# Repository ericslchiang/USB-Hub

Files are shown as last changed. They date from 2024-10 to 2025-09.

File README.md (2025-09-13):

## CHIP-8 Emulator by ericslchiang
### March 18th 2025  

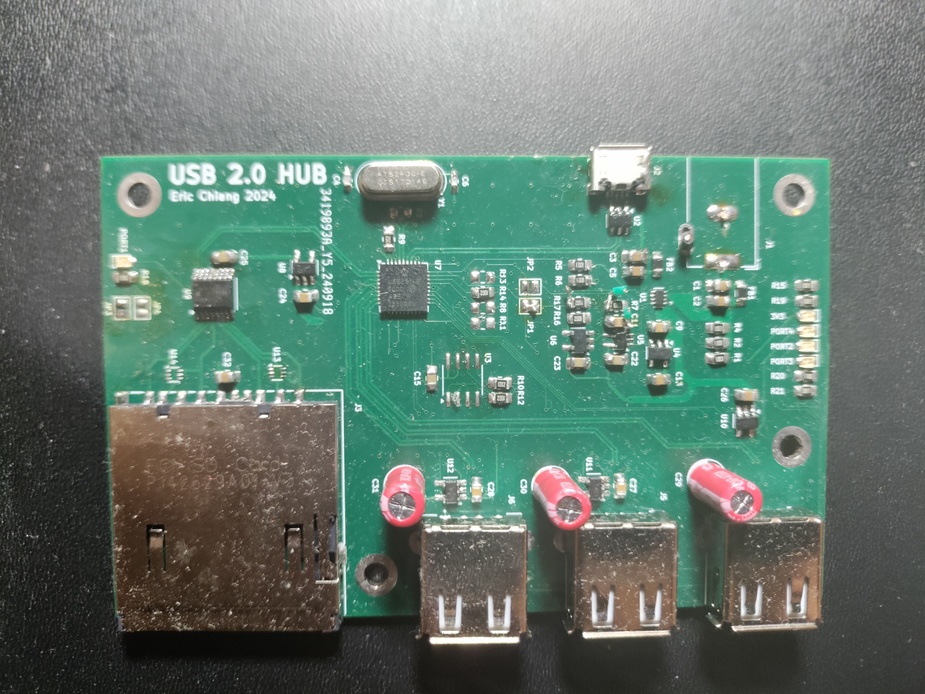
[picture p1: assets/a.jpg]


######
An USB 2.0 Hub with three downstream USB 2.0 Ports and one SD card slot. Built using a Microchip USB2514B for USB Hub control and a Genesys Logic GL823K USB 2.0 to SD card converter IC.  
Routed on a 4-layer PCB with controlled impedances and length controlled USB differential routes. All design files in KiCAD.

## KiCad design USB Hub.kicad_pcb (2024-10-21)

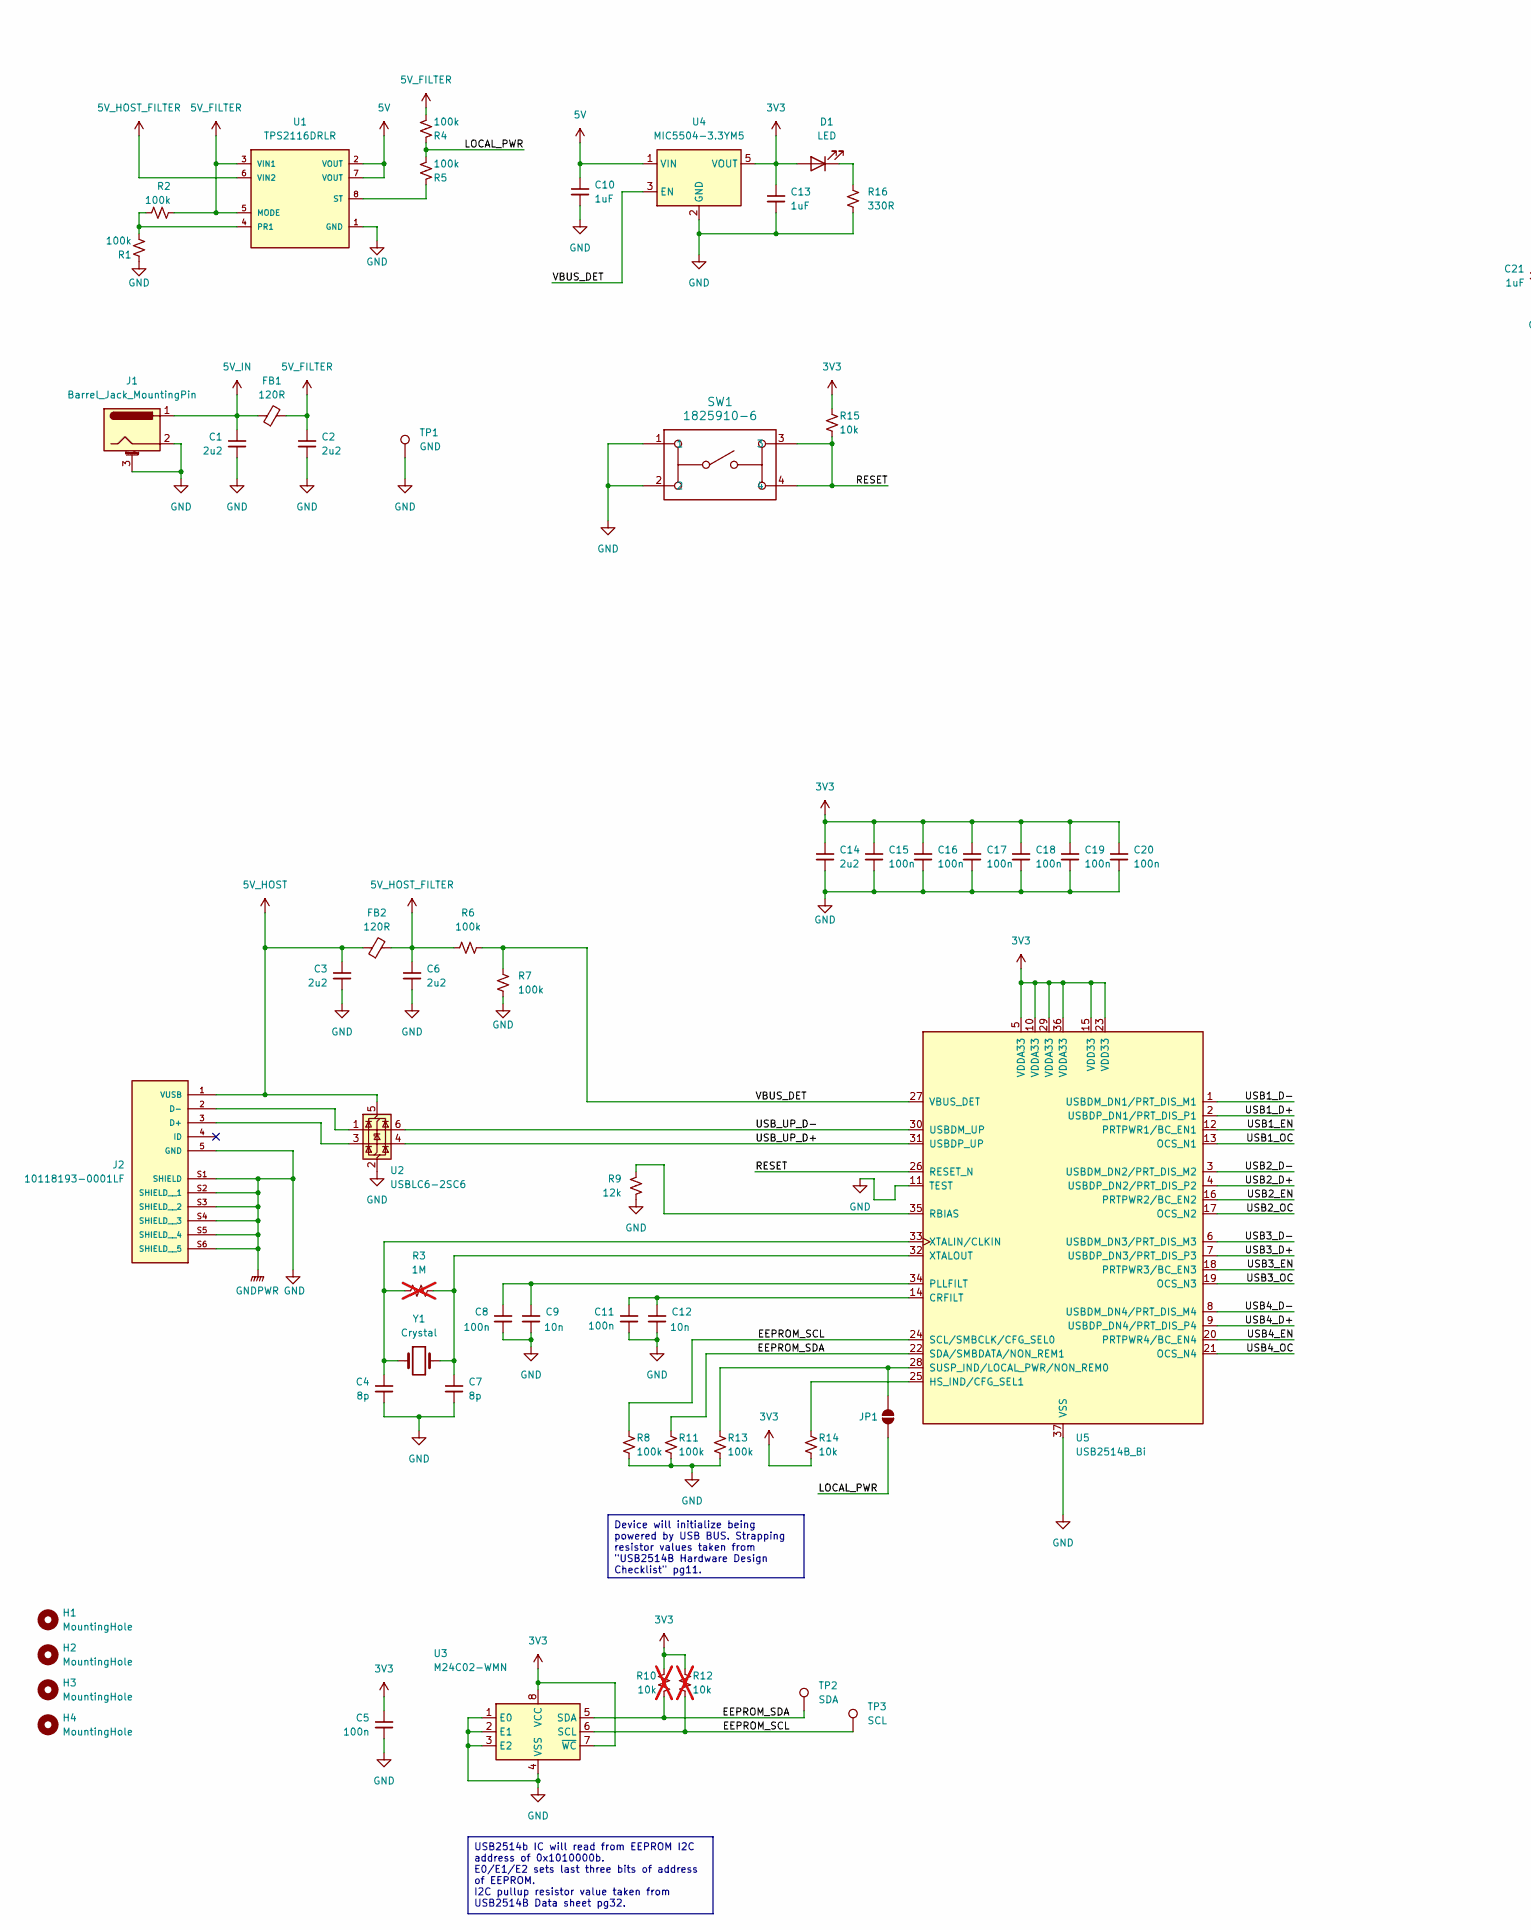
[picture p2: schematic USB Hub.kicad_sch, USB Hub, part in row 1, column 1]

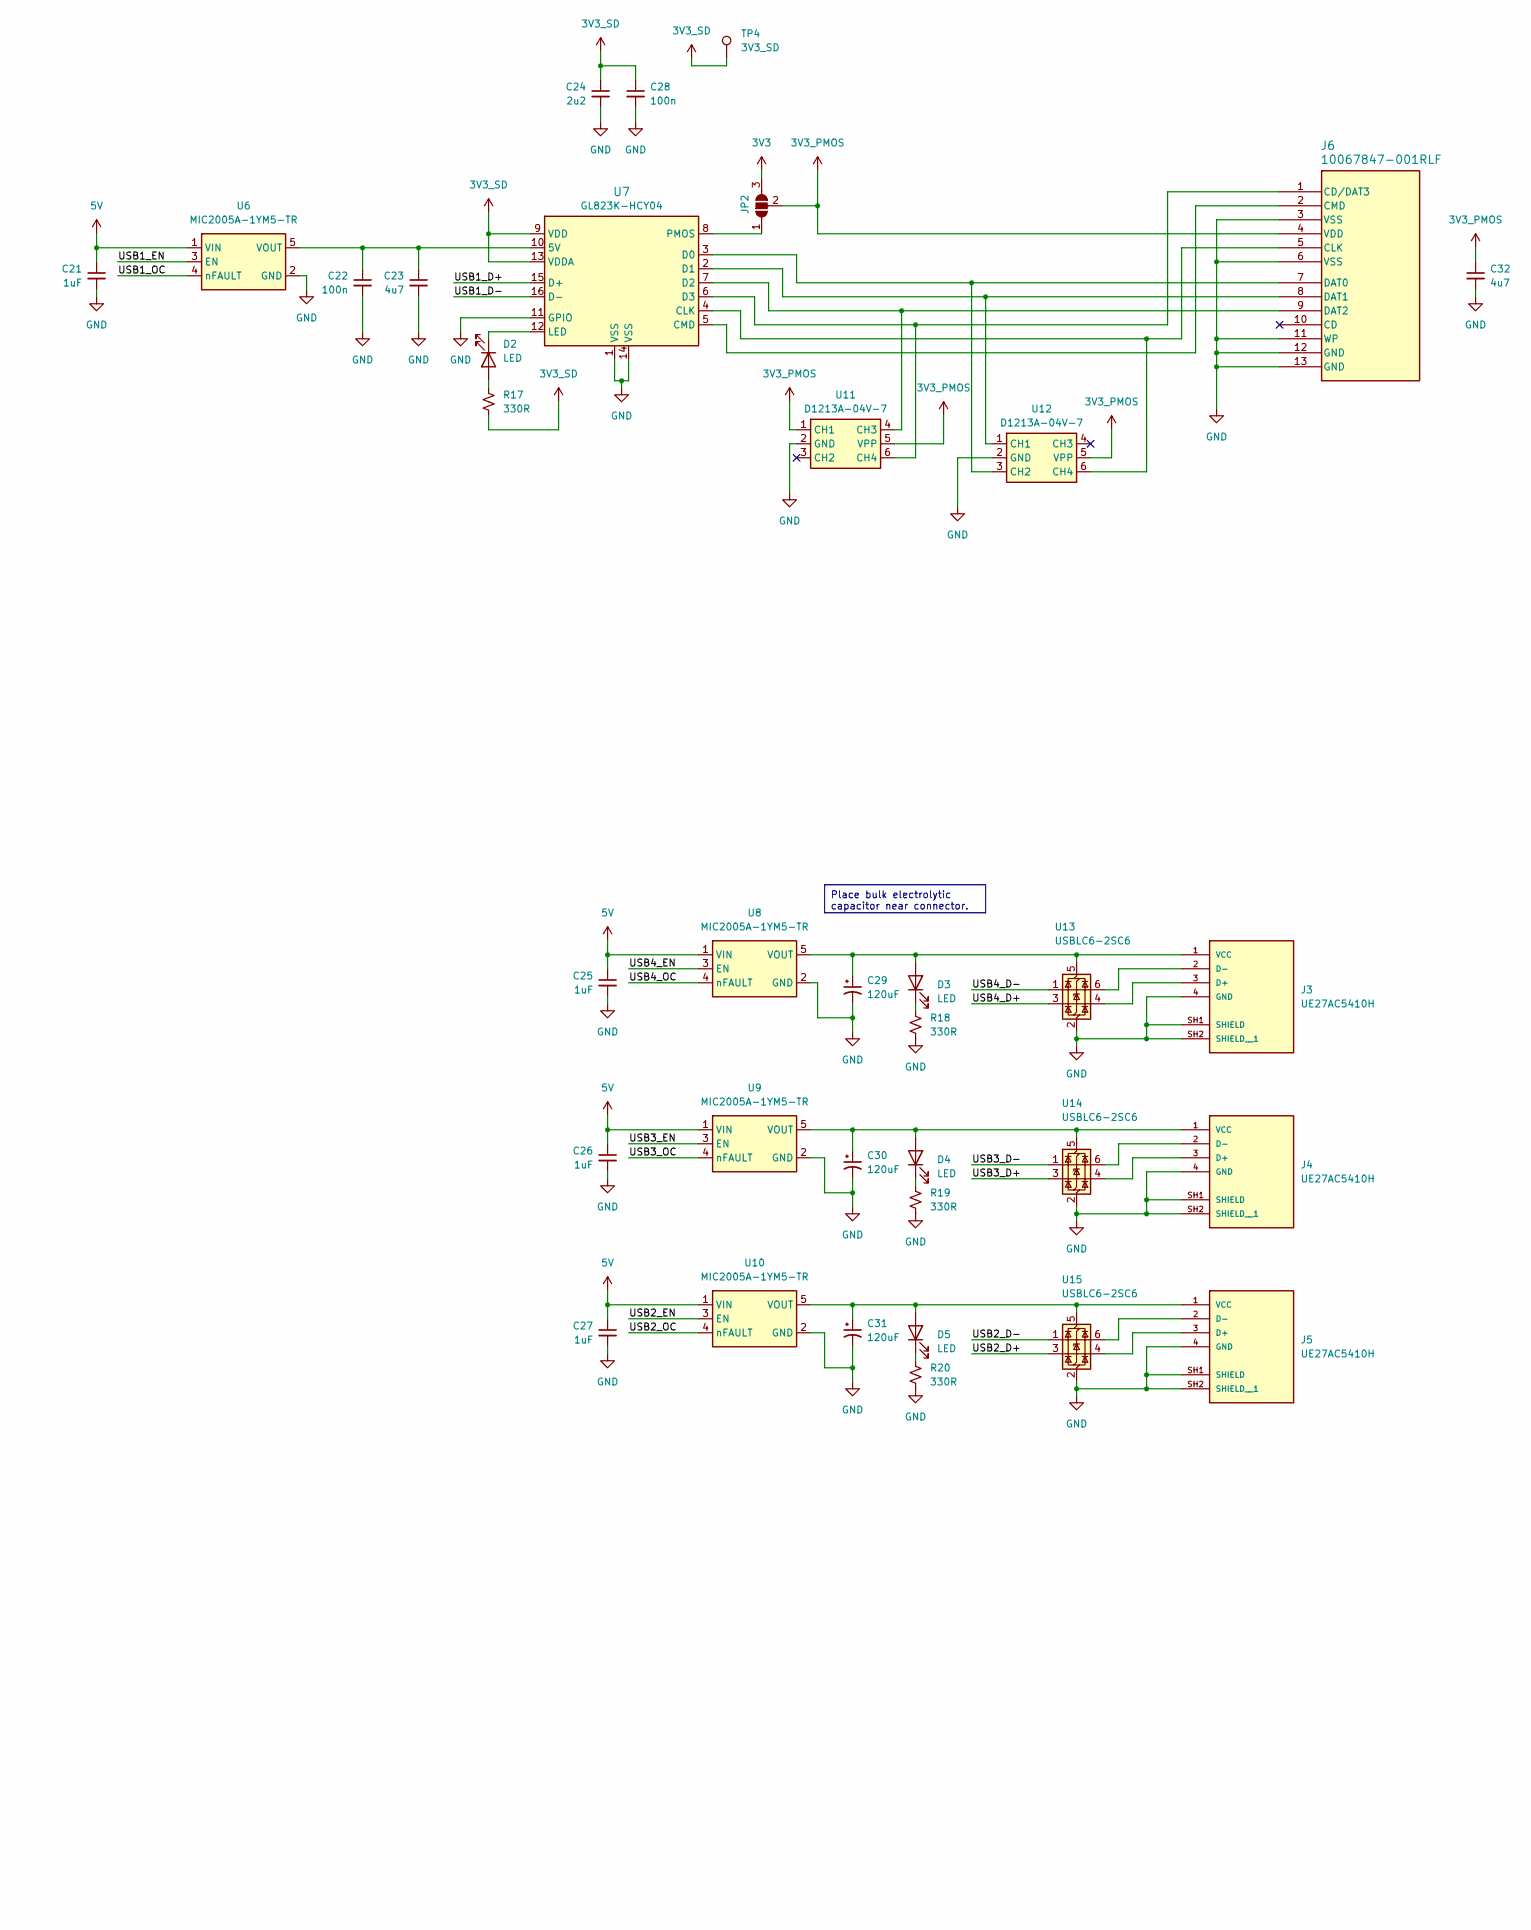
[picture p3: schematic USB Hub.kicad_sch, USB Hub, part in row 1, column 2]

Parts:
C1, C2, C3, C6, C14, C24: 2u2; C_0805_2012Metric_Pad1.18x1.45mm_HandSolder
C4, C7: 8p; C_0603_1608Metric_Pad1.08x0.95mm_HandSolder
C5, C8, C11, C15, C16, C17, C18, C19, C20, C22, C28: 100n; C_0805_2012Metric_Pad1.18x1.45mm_HandSolder
C9, C12: 10n; C_0805_2012Metric_Pad1.18x1.45mm_HandSolder
C10, C13, C21, C25, C26, C27: 1uF; C_0805_2012Metric_Pad1.18x1.45mm_HandSolder
C23, C32: 4u7; C_0805_2012Metric_Pad1.18x1.45mm_HandSolder
C29, C30, C31: 120uF; CP_Radial_D5.0mm_P2.00mm
D1, D2, D3, D4, D5: LED; LED_0603_1608Metric_Pad1.05x0.95mm_HandSolder
FB1, FB2: 120R; L_0805_2012Metric_Pad1.05x1.20mm_HandSolder
H1, H2, H3, H4: MountingHole; MountingHole_3.2mm_M3_DIN965_Pad
J1: Barrel_Jack_MountingPin; BarrelJack_GCT_DCJ200-10-A_Horizontal
J2: 10118193-0001LF; AMPHENOL_10118193-0001LF; PARTREV E
J3, J4, J5: UE27AC5410H; AMPHENOL_UE27AC5410H; PARTREV G
J6: 10067847-001RLF; 10067847-001RLF_AMP
JP1: SolderJumper-2_P1.3mm_Open_Pad1.0x1.5mm
JP2: SolderJumper_3_Open; SolderJumper-3_P2.0mm_Open_TrianglePad1.0x1.5mm_NumberLabels
R1, R2, R4, R5, R6, R7, R8, R11, R13: 100k; R_0805_2012Metric_Pad1.20x1.40mm_HandSolder
R3: 1M; R_0805_2012Metric; not fitted
R9: 12k; R_0805_2012Metric_Pad1.20x1.40mm_HandSolder
R10, R12: 10k; R_0805_2012Metric_Pad1.20x1.40mm_HandSolder; not fitted
R14, R15: 10k; R_0805_2012Metric_Pad1.20x1.40mm_HandSolder
R16, R17, R18, R19, R20: 330R; R_0805_2012Metric_Pad1.20x1.40mm_HandSolder
SW1: 1825910-6; SW4_1825910-B_TEC
TP1: GND; TestPoint_THTPad_D4.0mm_Drill2.0mm
TP2: SDA; TestPoint_THTPad_2.0x2.0mm_Drill1.0mm
TP3: SCL; TestPoint_THTPad_2.0x2.0mm_Drill1.0mm
TP4: 3V3_SD; TestPoint_THTPad_2.0x2.0mm_Drill1.0mm
U1: TPS2116DRLR; SOTFL50P160X60-8N; PARTREV A
U2, U13, U14, U15: USBLC6-2SC6; SOT-23-6
U3: M24C02-WMN; SOIC-8_3.9x4.9mm_P1.27mm
U4: MIC5504-3.3YM5; SOT-23-5
U5: USB2514B_Bi; QFN-36-1EP_6x6mm_P0.5mm_EP3.7x3.7mm_ThermalVias
U6, U8, U9, U10: MIC2005A-1YM5-TR; SOT-23-5_HandSoldering
U7: GL823K-HCY04; SSOP-16_3.9x4.9mm_P0.635mm
U11, U12: D1213A-04V-7; SOT-563
Y1: Crystal; XTAL_HC49P488W43L1150T466H350

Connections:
3V3: C5.1, C13.1, C14.1, C15.1, C16.1, C17.1, C18.1, C19.1, C20.1, D1.2 (A), JP2.3 (B), R10.1, R12.1, R14.2, R15.1, U3.7 (~WC), U3.8 (VCC), U4.5 (VOUT), U5.5 (VDDA33), U5.10 (VDDA33), U5.15 (VDD33), U5.23 (VDD33), U5.29 (VDDA33), U5.36 (VDDA33)
3V3_PMOS: C32.1, J6.4 (VDD), JP2.2 (C), U11.1 (CH1), U11.5 (VPP), U12.5 (VPP)
3V3_SD: C24.1, C28.1, R17.1, TP4.1, U7.9 (VDD), U7.13 (VDDA)
5V: C10.1, C21.1, C25.1, C26.1, C27.1, U1.2 (VOUT), U1.7 (VOUT), U4.1 (VIN), U6.1 (VIN), U8.1 (VIN), U9.1 (VIN), U10.1 (VIN)
5V_FILTER: C2.1, FB1.2, R2.2, R4.2, U1.3 (VIN1), U1.5 (MODE)
5V_HOST: C3.1, FB2.1, J2.1 (VUSB), U2.5 (VBUS)
5V_HOST_FILTER: C6.1, FB2.2, R6.2, U1.6 (VIN2)
5V_IN: C1.1, FB1.1, J1.1
/EEPROM_SCL: R8.1, R12.2, TP3.1, U3.6 (SCL), U5.24 (SCL/SMBCLK/CFG_SEL0)
/EEPROM_SDA: R10.2, R11.1, TP2.1, U3.5 (SDA), U5.22 (SDA/SMBDATA/NON_REM1)
/LOCAL_PWR: JP1.1 (A), R4.1, R5.2
/RESET: R15.2, SW1.3, SW1.4, U5.26 (RESET_N)
/USB1_D+: U5.2 (USBDP_DN1/PRT_DIS_P1), U7.15 (D+)
/USB1_D-: U5.1 (USBDM_DN1/PRT_DIS_M1), U7.16 (D-)
/USB1_EN: U5.12 (PRTPWR1/BC_EN1), U6.3 (EN)
/USB1_OC: U5.13 (OCS_N1), U6.4 (nFAULT)
/USB2_D+: U5.4 (USBDP_DN2/PRT_DIS_P2), U15.3 (I/O2)
/USB2_D-: U5.3 (USBDM_DN2/PRT_DIS_M2), U15.1 (I/O1)
/USB2_EN: U5.16 (PRTPWR2/BC_EN2), U10.3 (EN)
/USB2_OC: U5.17 (OCS_N2), U10.4 (nFAULT)
/USB3_D+: U5.7 (USBDP_DN3/PRT_DIS_P3), U14.3 (I/O2)
/USB3_D-: U5.6 (USBDM_DN3/PRT_DIS_M3), U14.1 (I/O1)
/USB3_EN: U5.18 (PRTPWR3/BC_EN3), U9.3 (EN)
/USB3_OC: U5.19 (OCS_N3), U9.4 (nFAULT)
/USB4_D+: U5.9 (USBDP_DN4/PRT_DIS_P4), U13.3 (I/O2)
/USB4_D-: U5.8 (USBDM_DN4/PRT_DIS_M4), U13.1 (I/O1)
/USB4_EN: U5.20 (PRTPWR4/BC_EN4), U8.3 (EN)
/USB4_OC: U5.21 (OCS_N4), U8.4 (nFAULT)
/USB_UP_D+: U2.4 (I/O2), U5.31 (USBDP_UP)
/USB_UP_D-: U2.6 (I/O1), U5.30 (USBDM_UP)
/VBUS_DET: R6.1, R7.1, U4.3 (EN), U5.27 (VBUS_DET)
GND: C1.2, C2.2, C3.2, C4.2, C5.2, C6.2, C7.2, C8.2, C9.2, C10.2, C11.2, C12.2, C13.2, C14.2, C15.2, C16.2, C17.2, C18.2, C19.2, C20.2, C21.2, C22.2, C23.2, C24.2, C25.2, C26.2, C27.2, C28.2, C29.2, C30.2, C31.2, C32.2, J1.2, J1.3 (MountPin), J2.5 (GND), J2.S1 (SHIELD), J2.S2 (SHIELD__1), J2.S3 (SHIELD__2), J2.S4 (SHIELD__3), J2.S5 (SHIELD__4), J2.S6 (SHIELD__5), J3.4 (GND), J3.SH1 (SHIELD), J3.SH2 (SHIELD__1), J4.4 (GND), J4.SH1 (SHIELD), J4.SH2 (SHIELD__1), J5.4 (GND), J5.SH1 (SHIELD), J5.SH2 (SHIELD__1), J6.3 (VSS), J6.6 (VSS), J6.11 (WP), J6.12 (GND), J6.13 (GND), R1.1, R7.2, R8.2, R9.1, R11.2, R13.2, R16.1, R18.1, R19.1, R20.1, SW1.1, SW1.2, TP1.1, U1.1 (GND), U2.2 (GND), U3.1 (E0), U3.2 (E1), U3.3 (E2), U3.4 (VSS), U4.2 (GND), U5.11 (TEST), U5.37 (VSS), U6.2 (GND), U7.1 (VSS), U7.11 (GPIO), U7.14 (VSS), U8.2 (GND), U9.2 (GND), U10.2 (GND), U11.2 (GND), U12.2 (GND), U13.2 (GND), U14.2 (GND), U15.2 (GND)
unnamed: D1.1 (K), R16.2
unnamed: D2.2 (A), R17.2
unnamed: D2.1 (K), U7.12 (LED)
unnamed: C29.1, D3.2 (A), J3.1 (VCC), U8.5 (VOUT), U13.5 (VBUS)
unnamed: D3.1 (K), R18.2
unnamed: C30.1, D4.2 (A), J4.1 (VCC), U9.5 (VOUT), U14.5 (VBUS)
unnamed: D4.1 (K), R19.2
unnamed: C31.1, D5.2 (A), J5.1 (VCC), U10.5 (VOUT), U15.5 (VBUS)
unnamed: D5.1 (K), R20.2
unnamed: J2.3 (D+), U2.3 (I/O2)
unnamed: J2.2 (D-), U2.1 (I/O1)
unnamed: J3.3 (D+), U13.4 (I/O2)
unnamed: J3.2 (D-), U13.6 (I/O1)
unnamed: J4.3 (D+), U14.4 (I/O2)
unnamed: J4.2 (D-), U14.6 (I/O1)
unnamed: J5.3 (D+), U15.4 (I/O2)
unnamed: J5.2 (D-), U15.6 (I/O1)
unnamed: J6.1 (CD/DAT3), U7.6 (D3), U11.6 (CH4)
unnamed: J6.5 (CLK), U7.4 (CLK), U12.6 (CH4)
unnamed: J6.2 (CMD), U7.5 (CMD)
unnamed: J6.7 (DAT0), U7.3 (D0), U12.3 (CH2)
unnamed: J6.8 (DAT1), U7.2 (D1), U12.1 (CH1)
unnamed: J6.9 (DAT2), U7.7 (D2), U11.4 (CH3)
unnamed: JP1.2 (B), R13.1, U5.28 (SUSP_IND/LOCAL_PWR/NON_REM0)
unnamed: JP2.1 (A), U7.8 (PMOS)
unnamed: R1.2, R2.1, U1.4 (PR1)
unnamed: R5.1, U1.8 (ST)
unnamed: C11.1, C12.1, U5.14 (CRFILT)
unnamed: R14.1, U5.25 (HS_IND/CFG_SEL1)
unnamed: C8.1, C9.1, U5.34 (PLLFILT)
unnamed: R9.2, U5.35 (RBIAS)
unnamed: C4.1, R3.1, U5.33 (XTALIN/CLKIN), Y1.1
unnamed: C7.1, R3.2, U5.32 (XTALOUT), Y1.2
unnamed: C22.1, C23.1, U6.5 (VOUT), U7.10 (5V)

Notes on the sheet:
Device will initialize being powered by USB BUS. Strapping resistor values taken from "USB2514B Hardware Design Checklist" pg11.
USB2514b IC will read from EEPROM I2C address of 0x1010000b. E0/E1/E2 sets last three bits of address of EEPROM. I2C pullup resistor value taken from USB2514B Data sheet pg32.
Place bulk electrolytic capacitor near connector.

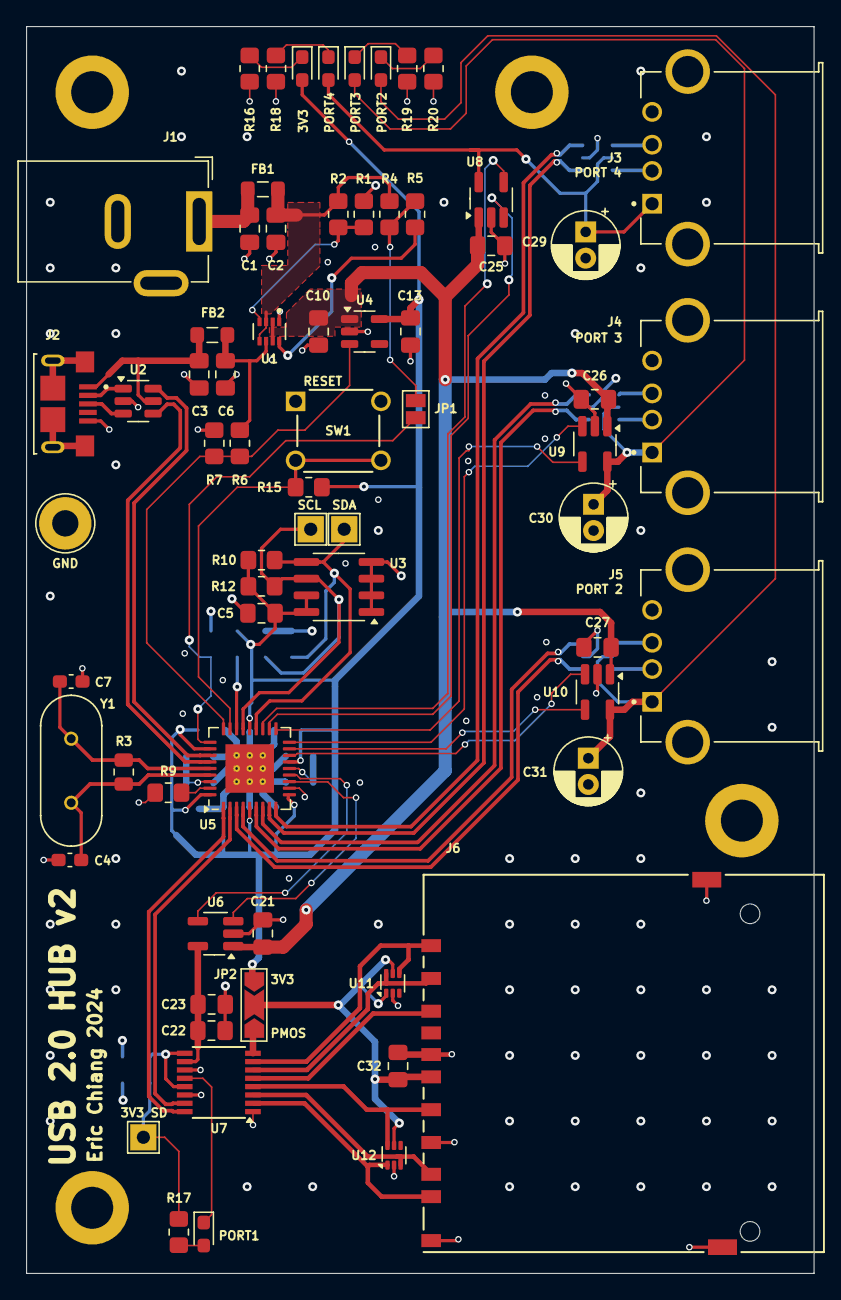
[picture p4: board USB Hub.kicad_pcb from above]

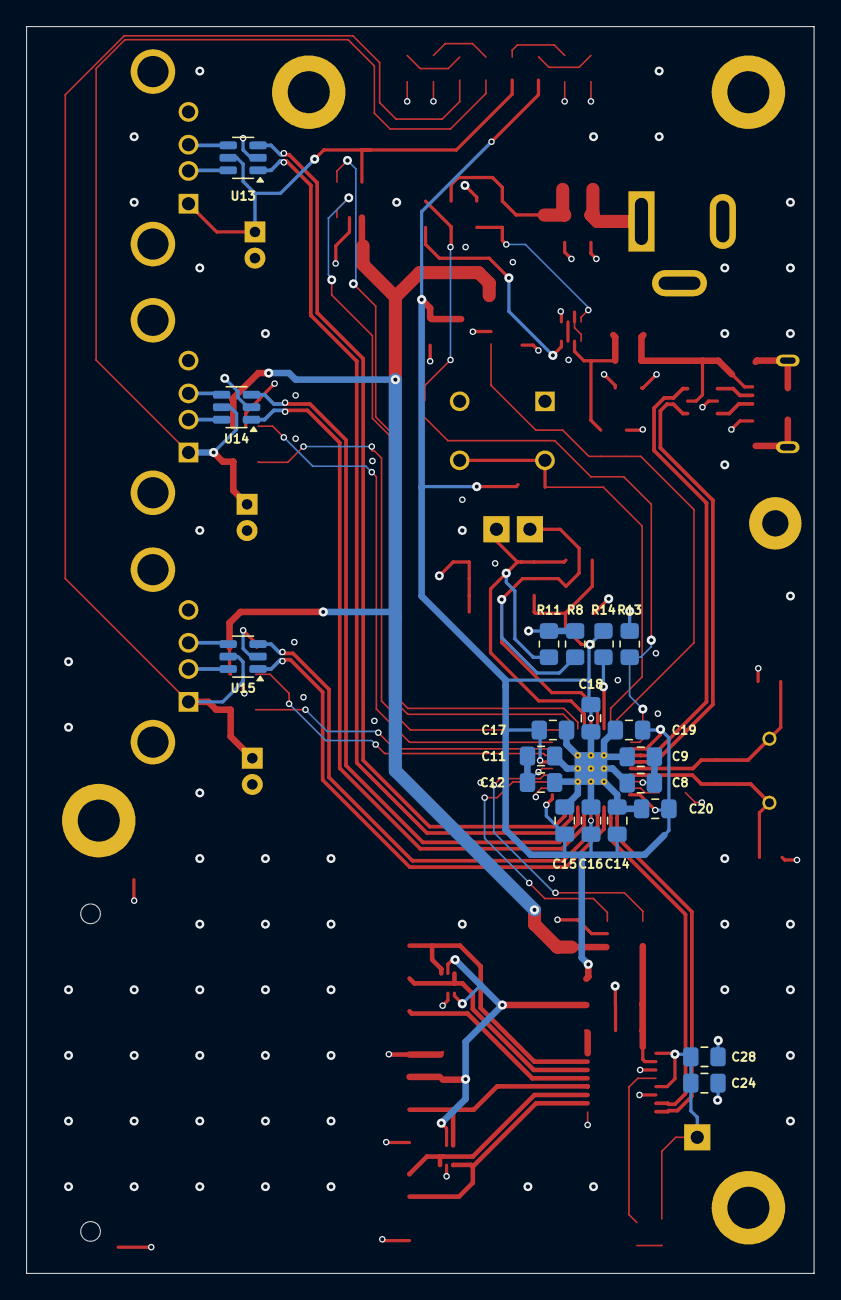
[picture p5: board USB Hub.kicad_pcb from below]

Board: 4 copper layers, 60.0 x 95.0 mm, 92 parts (20 on the bottom side), 66 nets.

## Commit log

2024-09-10 First revision of schematic
    [USB Hub.kicad_sch]
2024-09-15 first layout revision + some schematic rearrangements
    [USB Hub.kicad_pcb, USB Hub.kicad_sch]
2024-09-15 Fixed reference designator silkscreen and add copper pours to power section
    [USB Hub.kicad_pcb, USB Hub.kicad_sch]
2024-09-16 Fixed via stitching and sizes
    [USB Hub.kicad_pcb]
2024-10-21 v2 of USB Hub
    [USB Hub.kicad_pcb, USB Hub.kicad_sch]
